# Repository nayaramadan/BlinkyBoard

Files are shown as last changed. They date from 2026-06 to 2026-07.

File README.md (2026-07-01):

# BlinkyBoard
KiCad Blinky Board in the shape of a diamond!
There is also a drawn heart in the PCB to add a small personal touch to it.
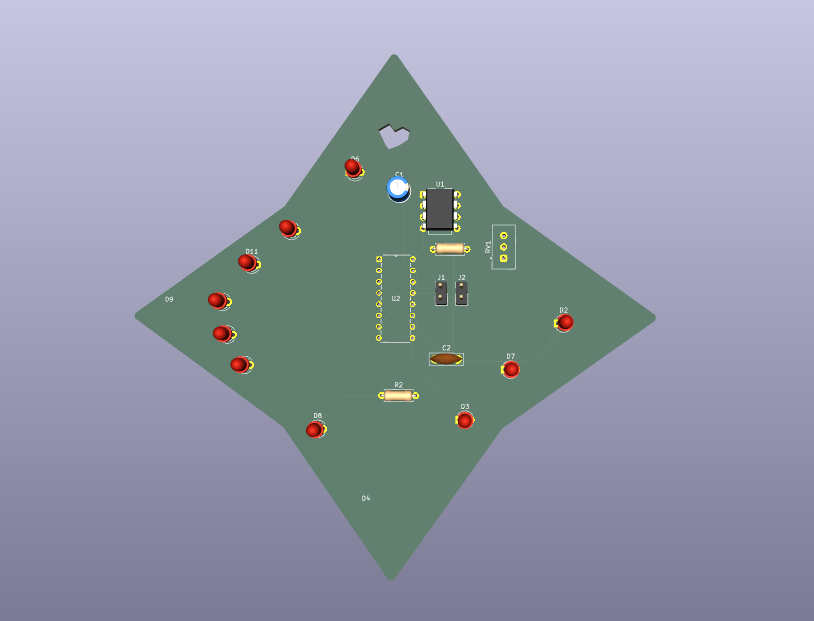
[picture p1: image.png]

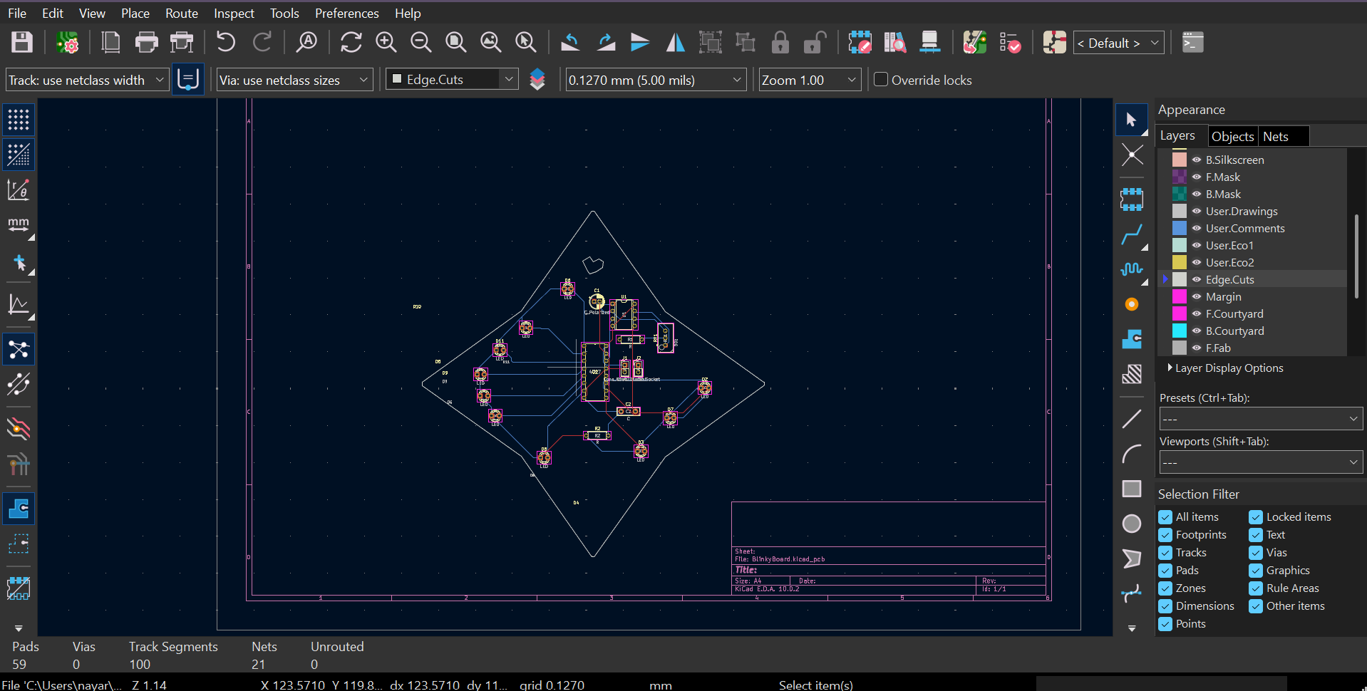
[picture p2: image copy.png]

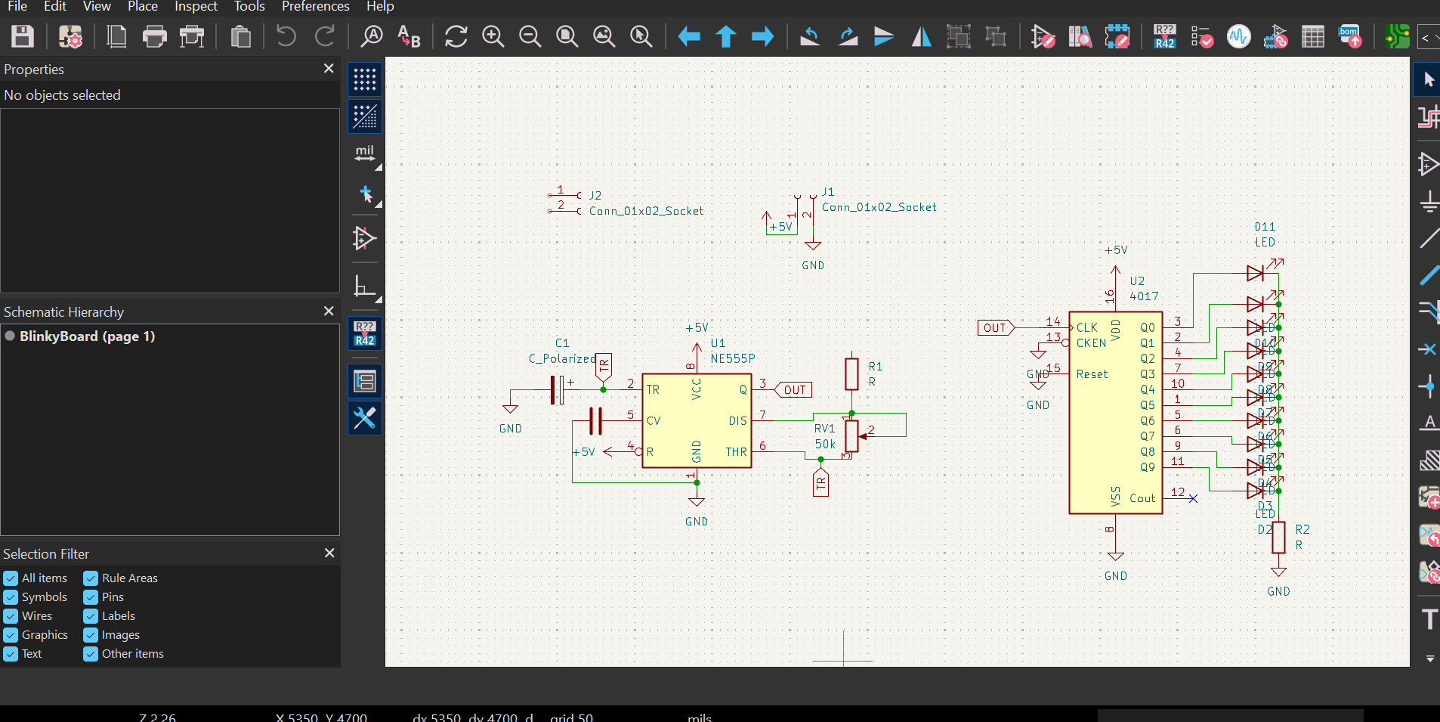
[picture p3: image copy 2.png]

BOM:
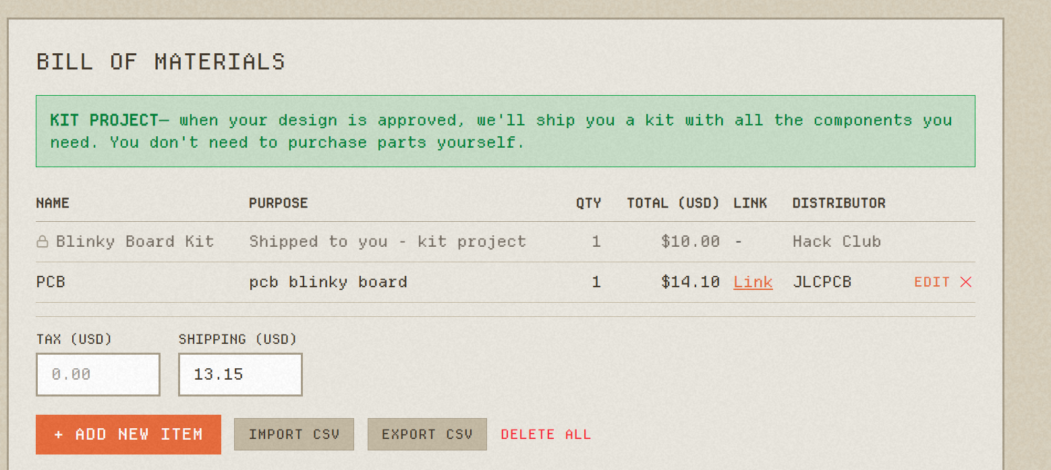
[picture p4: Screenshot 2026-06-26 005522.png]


<<<<<<< HEAD

Here's the BOM with components (also named BOMwithcomponents in the git)
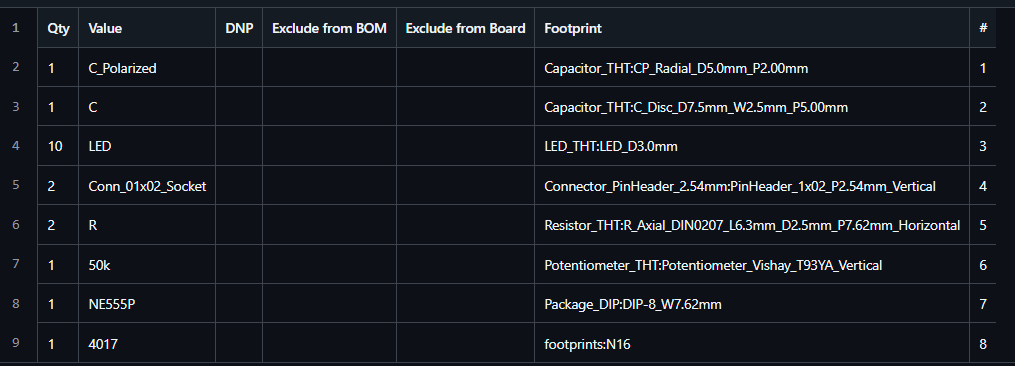
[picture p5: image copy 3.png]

=======

 This is a cool blinky board I made inspired by the stars!! It features a star shape along with a mini cut out heart. I started to build my first PCB, and definitely learned that! I leearned so much about KiCad, even from a simple project like this; I learned about footprints, schematics vs. pcb, and how to wire on a board! I loved making this project, it taught me a lot of the fundamentals for KiCad and I'm excited to build it

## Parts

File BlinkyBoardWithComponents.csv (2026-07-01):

Qty | Value | DNP | Exclude from BOM | Exclude from Board | Footprint | #
1 | C_Polarized |  |  |  | Capacitor_THT:CP_Radial_D5.0mm_P2.00mm | 1
1 | C |  |  |  | Capacitor_THT:C_Disc_D7.5mm_W2.5mm_P5.00mm | 2
10 | LED |  |  |  | LED_THT:LED_D3.0mm | 3
2 | Conn_01x02_Socket |  |  |  | Connector_PinHeader_2.54mm:PinHeader_1x02_P2.54mm_Vertical | 4
2 | R |  |  |  | Resistor_THT:R_Axial_DIN0207_L6.3mm_D2.5mm_P7.62mm_Horizontal | 5
1 | 50k |  |  |  | Potentiometer_THT:Potentiometer_Vishay_T93YA_Vertical | 6
1 | NE555P |  |  |  | Package_DIP:DIP-8_W7.62mm | 7
1 | 4017 |  |  |  | footprints:N16 | 8

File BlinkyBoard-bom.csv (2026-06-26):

Name | Purpose | Quantity | Total Cost (USD) | Link | Distributor
PCB | pcb blinky board | 1 | 14.10 | https://cart.jlcpcb.com/quote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 | JLCPCB

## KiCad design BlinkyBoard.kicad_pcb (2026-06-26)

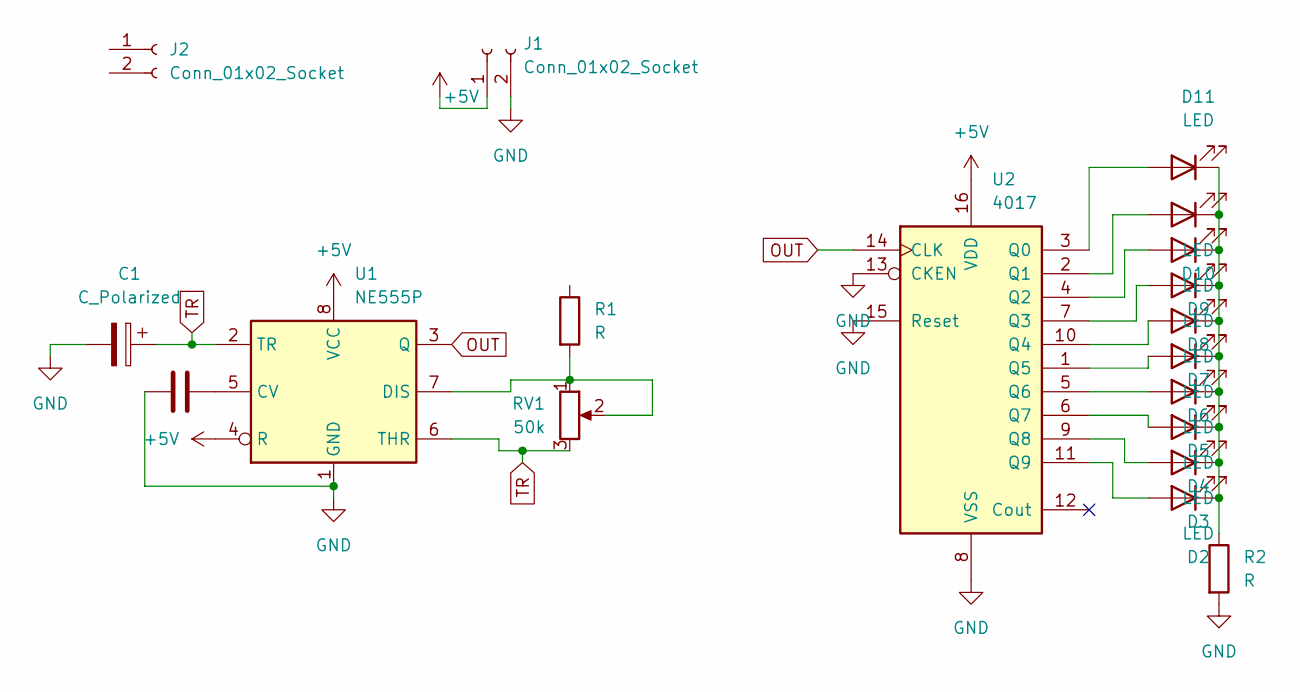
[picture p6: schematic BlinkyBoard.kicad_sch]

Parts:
C1: C_Polarized; CP_Radial_D5.0mm_P2.00mm
C2: C; C_Disc_D7.5mm_W2.5mm_P5.00mm
D2, D3, D4, D5, D6, D7, D8, D9, D10, D11: LED; LED_D3.0mm
J1, J2: Conn_01x02_Socket; PinHeader_1x02_P2.54mm_Vertical
R1, R2: R; R_Axial_DIN0207_L6.3mm_D2.5mm_P7.62mm_Horizontal
RV1: 50k; Potentiometer_Vishay_T93YA_Vertical
U1: NE555P; DIP-8_W7.62mm
U2: 4017; N16

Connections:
+5V: J1.1, U1.4 (R), U1.8 (VCC), U2.16 (VDD)
/<NO NET>: R1.1
GND: C1.2, C2.1, J1.2, R2.2, U1.1 (GND), U2.8 (VSS), U2.13 (CKEN), U2.15 (Reset)
unnamed: D2.2 (A), U2.11 (Q9)
unnamed: D3.2 (A), U2.9 (Q8)
unnamed: D4.2 (A), U2.6 (Q7)
unnamed: D5.2 (A), U2.5 (Q6)
unnamed: D6.2 (A), U2.1 (Q5)
unnamed: D7.2 (A), U2.10 (Q4)
unnamed: D8.2 (A), U2.7 (Q3)
unnamed: D9.2 (A), U2.4 (Q2)
unnamed: D10.2 (A), U2.2 (Q1)
unnamed: D2.1 (K), D3.1 (K), D4.1 (K), D5.1 (K), D6.1 (K), D7.1 (K), D8.1 (K), D9.1 (K), D10.1 (K), D11.1 (K), R2.1
unnamed: D11.2 (A), U2.3 (Q0)
unnamed: C2.2, U1.5 (CV)
unnamed: R1.2, RV1.1, RV1.2, U1.7 (DIS)
OUT: U1.3 (Q), U2.14 (CLK)
TR: C1.1, RV1.3, U1.2 (TR), U1.6 (THR)

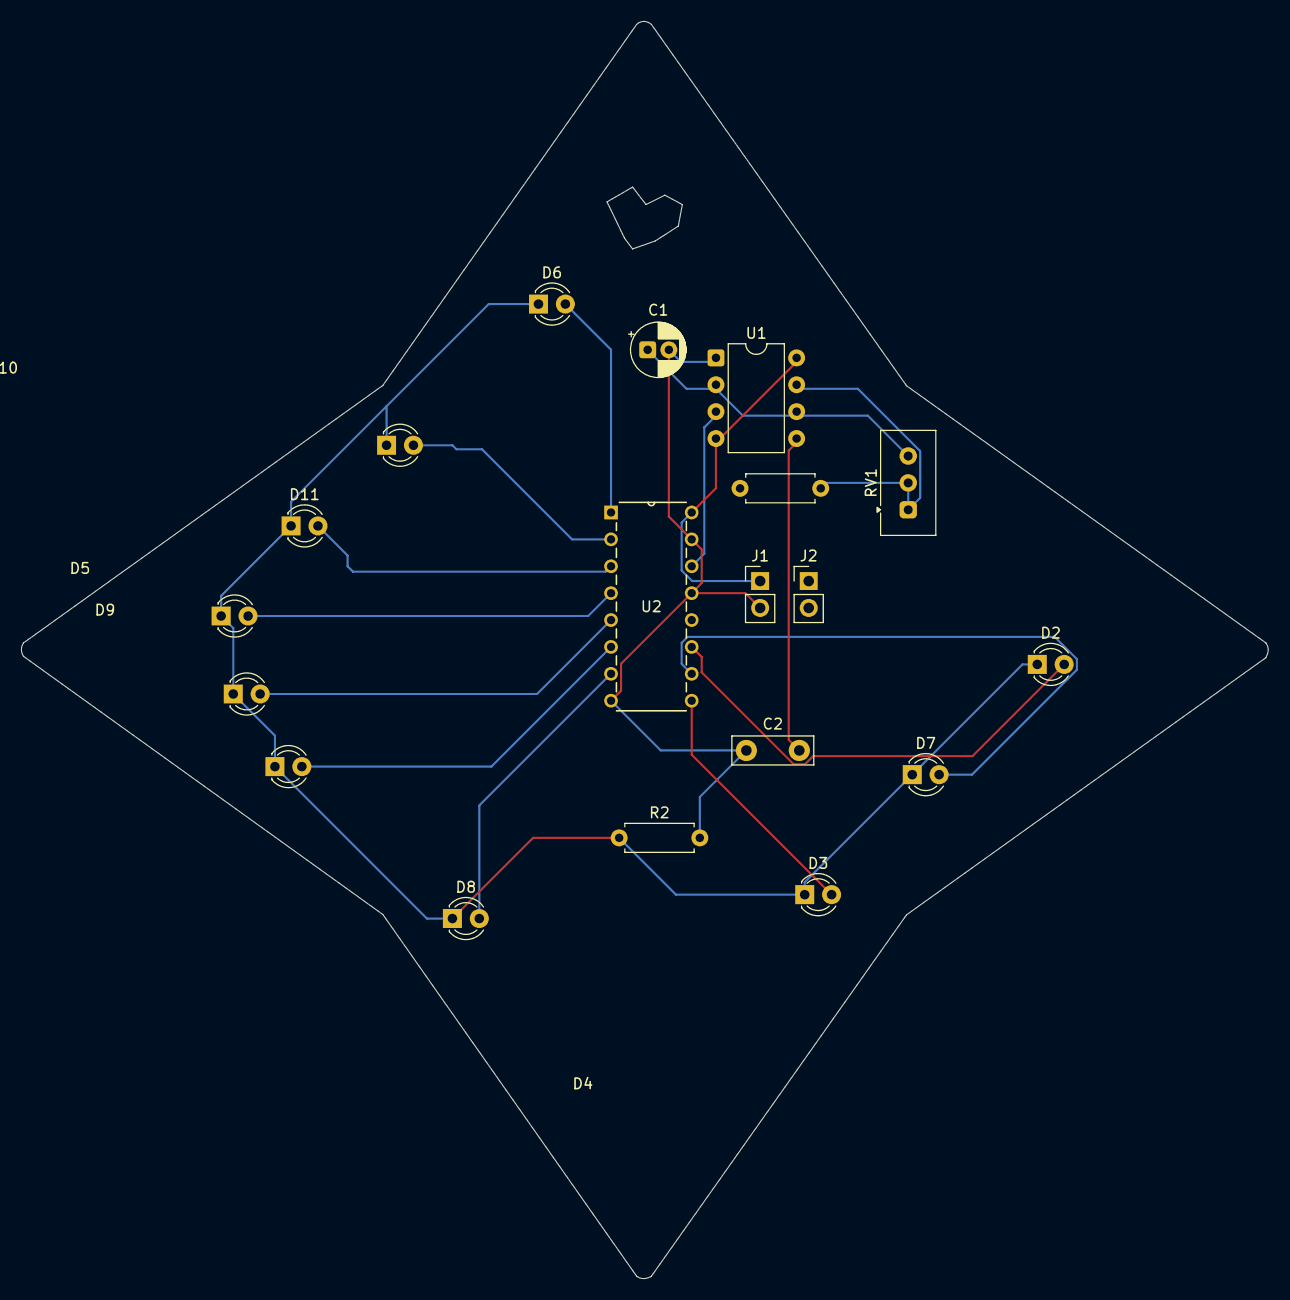
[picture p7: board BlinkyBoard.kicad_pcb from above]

Board: 2 copper layers, 117.8 x 118.7 mm, 19 parts (0 on the bottom side), 17 nets.

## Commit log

2026-04-12 kicad stuff
    [BlinkyBoard.kicad_pcb, BlinkyBoard.kicad_sch]
2026-06-02 Enhance README with board shape and design details
    Added a description of the board's shape and design.
2026-06-02 Forgot to upload my gerber file as a zip! Reuploaded
2026-06-24 Revert "Initial commit"
    This reverts commit e504e2252d0adfb80bc8437220d008c6d6f3c1aa.
    [BlinkyBoard.kicad_pcb, BlinkyBoard.kicad_sch]
2026-06-24 gonna reupload my files
    [BlinkyBoard-B_Cu.gbr, BlinkyBoard-B_Mask.gbr, BlinkyBoard-B_Paste.gbr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]
2026-06-26 final edits!
    [BlinkyBoard-bom.csv, BlinkyBoard.kicad_pcb, BlinkyBoard.kicad_sch]
2026-06-26 Enhance README with project details and insights
    Added project description and personal insights about learning KiCad.
2026-07-01 fixed the BOM!
